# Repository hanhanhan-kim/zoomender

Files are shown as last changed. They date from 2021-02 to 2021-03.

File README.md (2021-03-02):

# Zoomender

A simple plug-and-play device for ending Zoom calls—no software installation required! Will work for Linux, Windows, and Apple operating systems.

<!-- ![demo](docs/demo.gif) -->


## Hardware

### BOM

In addition to standard electronics equipment and access to a 3D-printer:

| Item | Price (USD) | Quantity | Source |
| --- | --- | --- | --- |
| Arduino Pro Micro* | 17.49 / 3 | 1 | Amazon <br />[ASIN B01MTU9GOB](https://www.amazon.com/HiLetgo-Atmega32U4-Bootloadered-Development-Microcontroller/dp/B01MTU9GOB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) |
| big dome push-button (red) | 11.95 | 1 | Sparkfun <br />[COM-09181](https://www.sparkfun.com/products/9181) |
| SP3T switch | 1.25 | 1 | DigiKey <br />[450-1571-ND](https://www.digikey.com/en/products/detail/te-connectivity-alcoswitch-switches/1825255-8/1202283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) |
| SPDT switch** | 0.65 | 1 | DigiKey <br />[EG1903-ND](https://www.digikey.com/en/products/detail/e-switch/EG1218/101726) |

**Note:* I used an Arduino Pro Micro clone, to cut down on price. So long as it has an ATmega 32U4 processor, it should be able to spoof a HID just as well as the real thing, no problem. 

***Note*: The SPDT switch isn’t really necessary. It just controls the LED built into the push button. I understand some people have their computers near their bed, however, and so the option to turn off the LED is sometimes desirable. 

### Circuit

A literal schematic is shown below. The exact GND pins that were used are depicted (not that it matters):

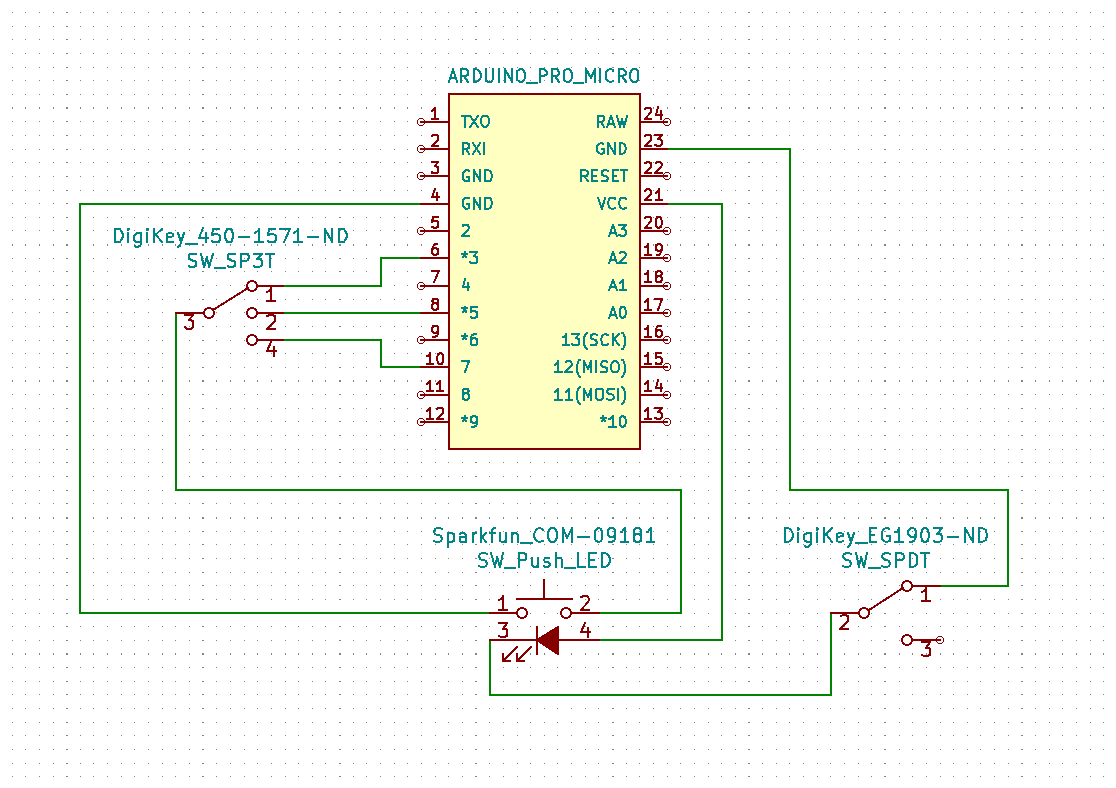
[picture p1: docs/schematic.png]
schematic


A complementary photograph:

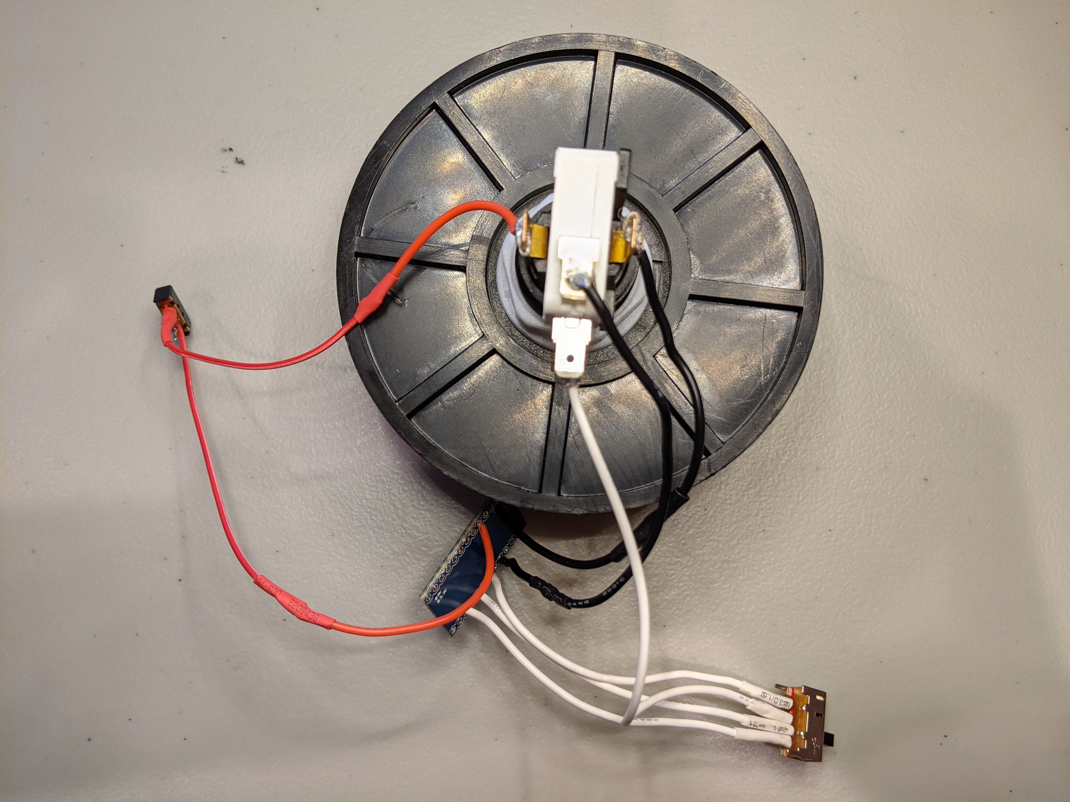
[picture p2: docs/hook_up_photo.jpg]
hook-up


### Assembly

1. Print the [`main.stl`](/hardware/STLs/main.stl) and the [`base.stl`](/hardware/STLs/base.stl). I used the default settings for PLA at 0.2 um layer height on my Prusa MK3S. 
2. Solder or crimp the connections together, as illustrated in the schematic. Making connections on the terminals of the small SPDT and SP3T switches can be a little tricky. I found that female crimp pins meant for 0.1” housing (like the kind you find on breadboard jumper cables) worked well, when combined with some solder. I then added some heat-shrink to prevent shorting the switch terminals. Alternatively, you can take a more professional approach.
3. Press-fit the push-button, switches, and Pro Micro into their respective slots of the main body. If your print settings were well tuned, the components should fit snugly, without complaints. Otherwise, don’t be afraid to use some epoxy or hot glue. 
4. Screw the base into the bottom of the main, via the printed threads. 

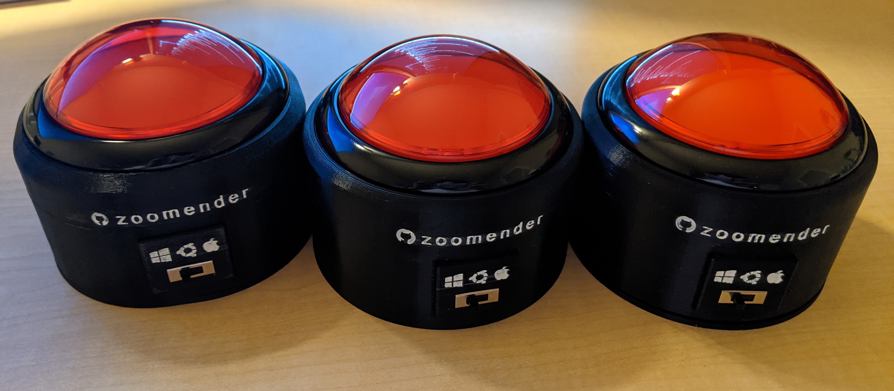
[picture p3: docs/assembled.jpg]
assembled


## Firmware

Just upload the [`firmware.ino`](/firmware/firmware.ino) file via the Arduino IDE and you’re ready to go! 

## Extensions

A wireless Bluetooth version is very possible, but it adds to the price. We just need to replace the Arduino Pro Micro board with one that is Bluetooth-capable. Adafruit’s version of an ESP32 board ([SKU 3405](https://www.adafruit.com/product/3405)) supports both classic and low-energy Bluetooth connections, and can easily spoof a HID, when combined with [T-vK’s ESP32 BLE Keyboard library](https://github.com/T-vK/ESP32-BLE-Keyboard). It costs over three times that of a single Pro Micro clone, however. Cheaper ESP32 boards can be found on Amazon and AliExpress, but the Adafruit one is nice because when both the LiPo battery and the USB are connected, the board will automatically switch over to USB for power, while simultaneously charging the battery at 200 mA—the sort of behaviour we might expect out of a consumer-grade Bluetooth device. Simultaneous delivery of multiple power sources on cheaper ESP32 boards can damage the board, and in some cases, the host computer. I’ll update the repo with a Bluetooth alternative, sometime in the future.

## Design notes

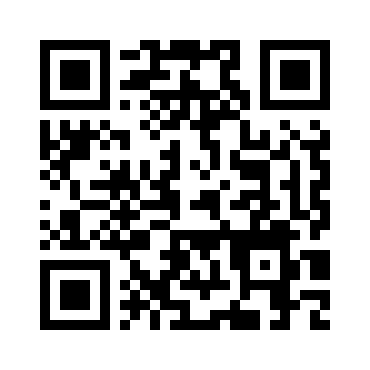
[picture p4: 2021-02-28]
assets/link.png

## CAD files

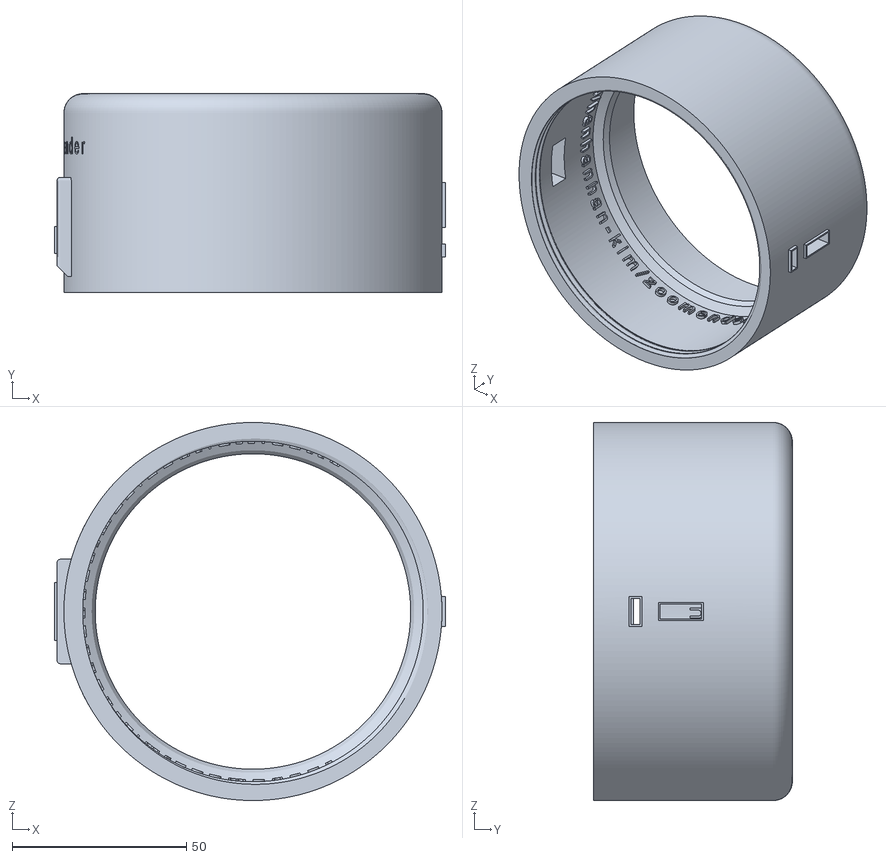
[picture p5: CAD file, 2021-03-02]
hardware/STLs/main.stl
112.2 x 57.0 x 108.5

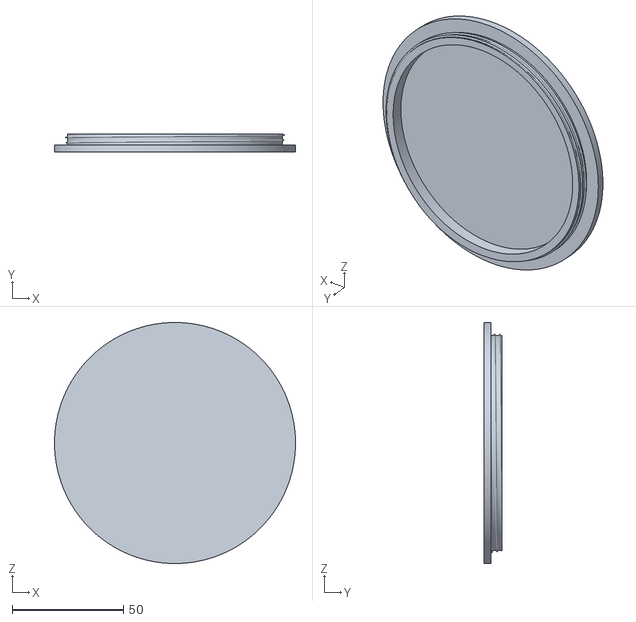
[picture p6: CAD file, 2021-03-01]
hardware/STLs/base.stl
108.5 x 8.00 x 108.5

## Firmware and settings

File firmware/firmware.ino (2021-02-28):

// Ends Zoom call and exits the Zoom program for any OS.  

# include "Keyboard.h"

const int end_zoom_win_pin = 3;
const int end_zoom_lin_pin = 5;
const int end_zoom_mac_pin = 7;

int old_win_button_state = HIGH;
int old_lin_button_state = HIGH;
int old_mac_button_state = HIGH;


// Pull-ups protect from floating noise:
void setup() {
  
    pinMode(end_zoom_win_pin, INPUT_PULLUP); 
    pinMode(end_zoom_lin_pin, INPUT_PULLUP);
    pinMode(end_zoom_mac_pin, INPUT_PULLUP);
    Keyboard.begin();
    
}


void loop() {

    int win_button_state = digitalRead(end_zoom_win_pin);
    int lin_button_state = digitalRead(end_zoom_lin_pin);
    int mac_button_state = digitalRead(end_zoom_mac_pin);
    
    // Macro for killing Zoom on Windows:    
    if ((old_win_button_state != win_button_state) && 
    (lin_button_state == HIGH) && 
    (mac_button_state == HIGH) && 
    (win_button_state == LOW)) {
      
        // End Zoom call:        
        Keyboard.press(KEY_LEFT_ALT);
        Keyboard.press('q');
        Keyboard.releaseAll();
        delay(200);
        Keyboard.press(KEY_TAB);
        Keyboard.releaseAll();
        Keyboard.press(KEY_RETURN);
        Keyboard.releaseAll();
        delay(200);
        // Exit Zoom:
        Keyboard.press(KEY_LEFT_ALT);
        Keyboard.press(KEY_F4);
        Keyboard.releaseAll();
        delay(500); 
        
    }
    
    old_win_button_state = win_button_state;

    // Macro for killing Zoom on Linux:
    if ((old_lin_button_state != lin_button_state) && 
    (win_button_state == HIGH) && 
    (mac_button_state == HIGH) &&
    (lin_button_state == LOW)) {
      
        // End Zoom call:
        Keyboard.press(KEY_LEFT_ALT);
        Keyboard.press('q');
        Keyboard.releaseAll();
        Keyboard.press(KEY_RETURN);
        Keyboard.releaseAll();
        // Exit Zoom: 
        Keyboard.press(KEY_LEFT_CTRL);
        Keyboard.press('q');
        Keyboard.releaseAll();
        delay(500);
        
    }
    
    old_lin_button_state = lin_button_state;

    // Macro for killing Zoom on Mac:
    if ((old_mac_button_state != mac_button_state) && 
    (win_button_state == HIGH) && 
    (lin_button_state == HIGH) && 
    (mac_button_state == LOW)) {

        // End Zoom call:
        Keyboard.press(KEY_LEFT_GUI);
        Keyboard.press('w');
        Keyboard.releaseAll();
        Keyboard.press(KEY_RETURN);
        Keyboard.releaseAll();
        // Exit Zoom: 
        Keyboard.press(KEY_LEFT_GUI);
        Keyboard.press('q');
        Keyboard.releaseAll();
        delay(500);
        
    }

    old_mac_button_state = mac_button_state;

} 

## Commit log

2021-02-27 specify states for other macros to HIGH, bc diverter switch
2021-02-27 add svgs and stls
    [base.stl, main.stl]
2021-02-28 fix button dia, use threads instead of press-fit, fix usb hole
    [base.stl, main.stl]
2021-02-28 fix base, add full link, move USB port
    [base.stl, main.stl]
2021-02-28 tweak win logo
    [main.stl]
2021-03-01 add kicad stuff
    [zoomender.kicad_pcb, zoomender.sch]
2021-03-01 add circuit schematic
2021-03-01 change to true cylinders
    [base.stl, main.stl]
2021-03-02 seal gaps
    [main.stl]
2021-03-02 add gif and assembled photo
